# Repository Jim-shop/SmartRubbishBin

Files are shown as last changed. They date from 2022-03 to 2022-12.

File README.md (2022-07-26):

# SmartRubbishBin（智能倾倒垃圾桶）

## 仓库结构（暂定）

- `📂Arduino`文件夹存放Arduino代码
- `📂CarModel`文件夹存放小车SolidWorks模型
- `📂ROS`文件夹存放与ROS相关的代码
- `📂Tutorial`中记录一些学习笔记
- `📄.gitignore`中填写不需要被git管理的文件/文件夹
- `📄Makefile`配置自动构建或执行自动化任务
- `📄README.md`就是本文件

## 开发环境

- Ubuntu == 20.04 ~ 20.04.4
- Arduino IDE >= 1.8.19
- ROS1-Noetic-Desktop-Full（自带OpenCV)
- ros-noetic-serial包
- SolidWorks == 2021
- Arduino Uno 一片
- L298N 一片
- 激光雷达一个

## 食用指南

### 1. 首先将仓库克隆到本地：

```bash
cd 父路径（自选）
git clone git@github.com:Jim-shop/SmartRubbishBin.git
```
> 没有配置公钥的话可以用HTTPS克隆。

这样，`git`会在自选的`父路径`下新建一个以这个仓库名命名的文件夹，然后将仓库内容以及文件历史信息等克隆到这个文件夹里。

注意，此仓库会用到一些预训练的神经网络，这些神经网络的权重文件比较大，不方便上传Github，请在网络上下载后手动放到相应地方。

### 2. 配置环境

#### （1）Arduino IDE 从官网下载安装
apt源得到的版本较为老旧。
#### （2）Ros Noetic和Serial包参考以下命令安装
```bash
sudo apt install ros-noetic-desktop-full
sudo apt install ros-noetic-serial
```
#### （3）给设备起别名，防止设备号乱了
首先执行
```bash
lsusb
```
得到设备号如`10c4:ea60`。
进入`cd /etc/udev/rules.d`进入目录，新建一个`usb.rules`文件，内容为
```shell
KERNEL=="ttyUSB*",ATTRS{idVendor}=="10c4",ATTRS{idProduct}=="ea60",MODE:="0777",SYMLINK+="laser"
KERNEL=="ttyUSB*",ATTRS{idVendor}=="1a86",ATTRS{idProduct}=="7523",MODE:="0777",SYMLINK+="uno"
```
然后重启udev：
```bash
service udev reload
service udev restart
```
重新插拔USB设备即可。

### 3. 编译
   
为了节省空间和保护隐私，仓库里只有源代码，要生成可执行程序，请参照以下操作：

#### （1）逐一构建
- 如果要生成ROS的可执行文件，请：
    ```bash
    cd 刚克隆下来的仓库路径/ros/
    catkin_make
    ```
- 如果要生成Arduino固件，请直接使用Arduino IDE打开ino文件进行编译烧录。

#### （2）批量构建
将来可能有很多不同种类的文件/代码（当然现在只有ROS代码和Arduino代码两种），逐一编译生成很麻烦。因此在仓库根目录下配置了一个`Makefile`，在其中填入了各种文件的编译方法，只要在根目录下输入：
```bash
cd 刚克隆下来的仓库路径/
make
```
这样所有项目就可以一次性编译完成。

> 顺便，`Makefile`中也配置了清理功能，
> 只要在根目录下执行：
> ```bash
> make only_source
> ```
> 就可以删除编译结果，只保留源代码。

### 4. 开发

参见[Git协作开发指南](Tutorial/Git协作开发指南.md)。

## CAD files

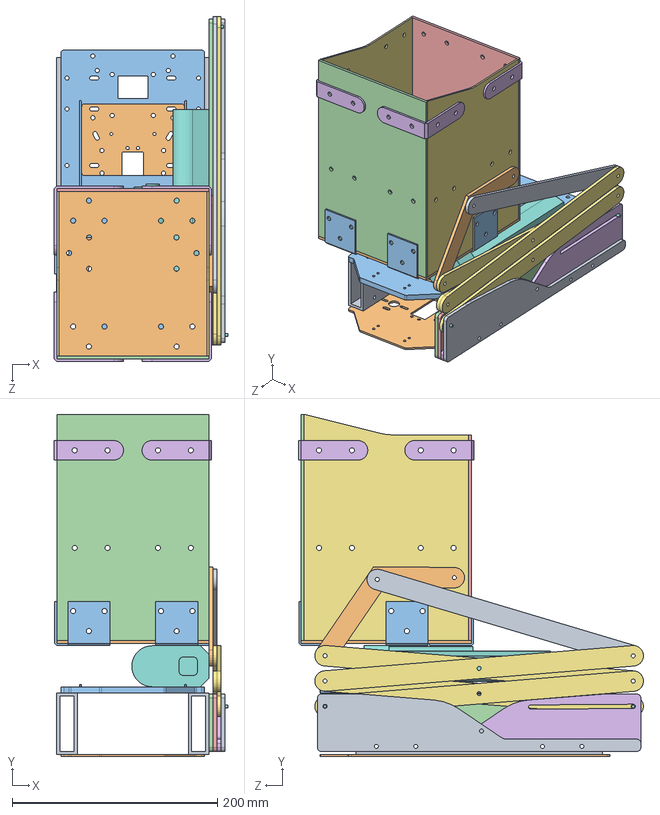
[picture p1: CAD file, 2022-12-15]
CarModel/完整机构.SLDASM
169.0 x 333.2 x 335.8 mm
钢扁管（x2） x 2
小车底板
小车底板(3d打印二层）
滑槽板（内侧）
滑槽板（中间）
滑槽板（外侧）
连杆 x 4
塞打螺栓 x 2
倾倒杆2
底板
角铁2 x 6
侧面板
侧面板2
角铁1 x 4
侧板2 x 2
底座
滑槽板（最外）
倾倒杆

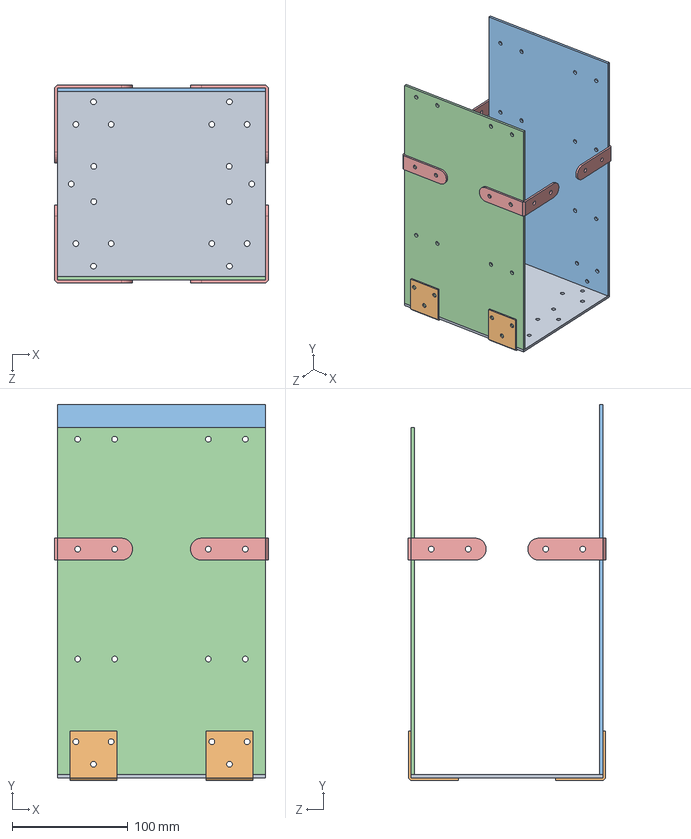
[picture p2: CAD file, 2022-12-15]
CarModel/垃圾桶2.0.SLDASM
185.0 x 325.0 x 171.0 mm
底板
角铁2 x 4
侧面板
侧面板2
角铁1 x 4

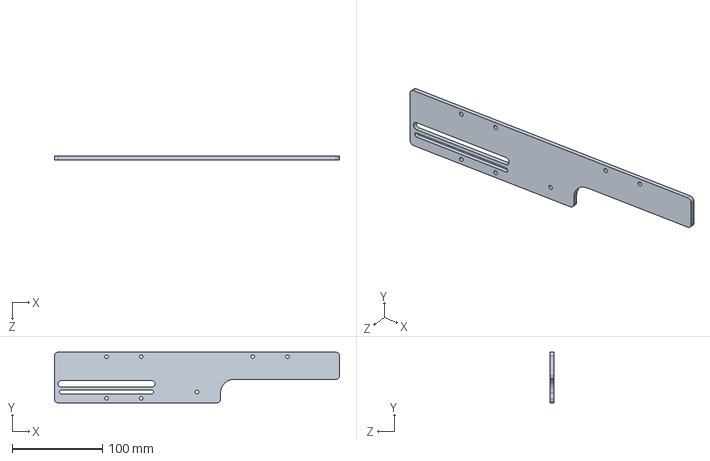
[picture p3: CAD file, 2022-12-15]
CarModel/滑槽板（外侧）.SLDPRT
315.0 x 56.0 x 4.00 mm

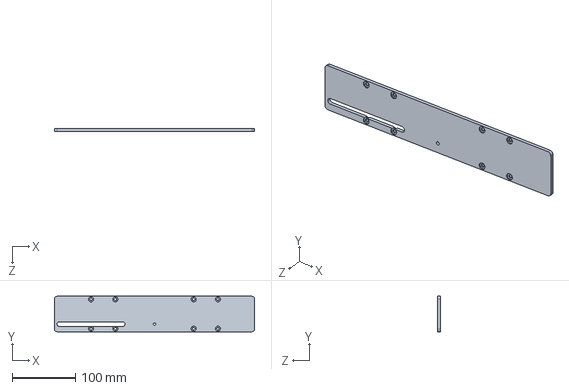
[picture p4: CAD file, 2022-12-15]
CarModel/滑槽板（内侧）.SLDPRT
315.0 x 56.0 x 4.00 mm

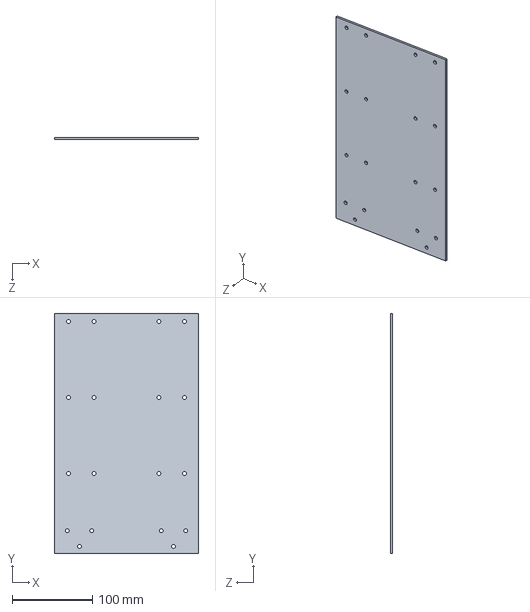
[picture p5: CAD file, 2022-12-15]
CarModel/侧面板2.SLDPRT
180.0 x 300.0 x 3.00 mm

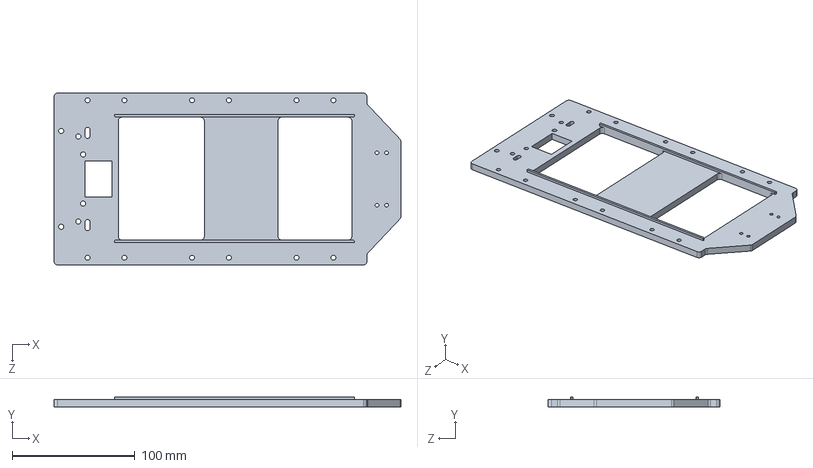
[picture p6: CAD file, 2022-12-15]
CarModel/小车底板(3d打印二层）.SLDPRT
282.3 x 8.00 x 140.0 mm

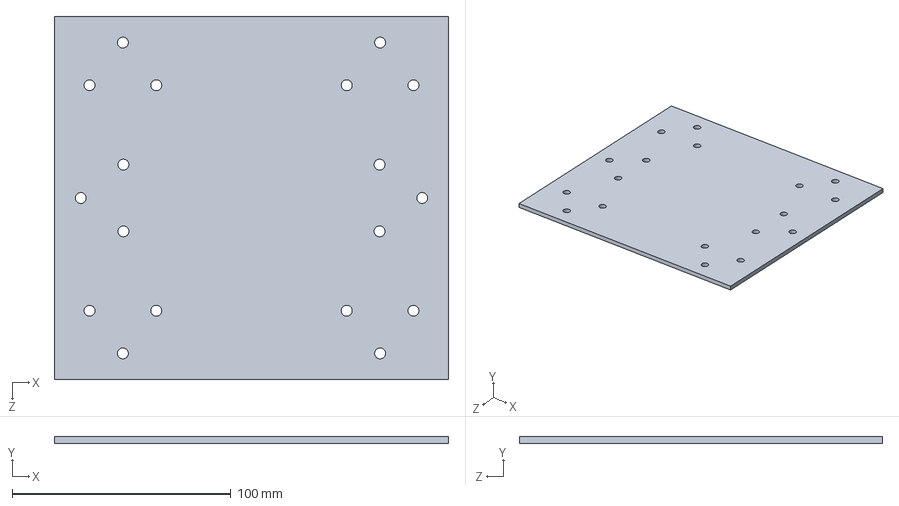
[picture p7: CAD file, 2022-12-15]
CarModel/底板.SLDPRT
180.0 x 3.00 x 166.0 mm

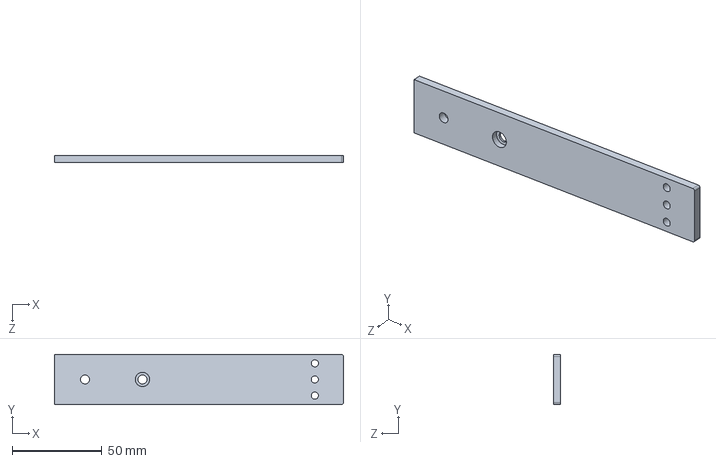
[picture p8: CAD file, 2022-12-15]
CarModel/推动杆.SLDPRT
161.0 x 27.8 x 4.00 mm

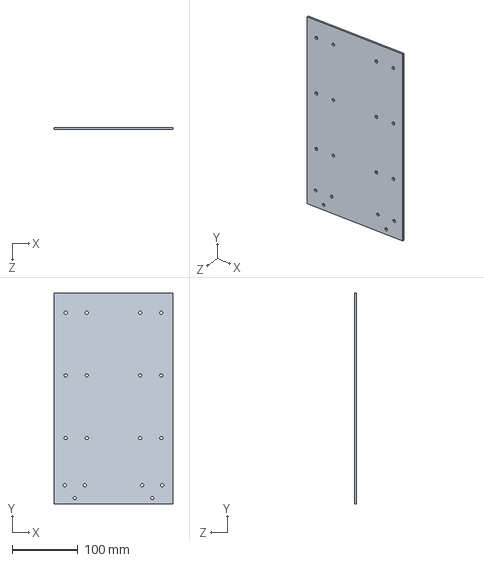
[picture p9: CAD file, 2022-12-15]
CarModel/侧面板.SLDPRT
180.0 x 320.0 x 3.00 mm

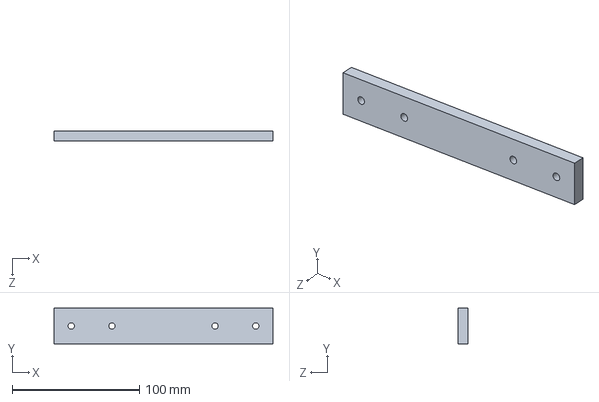
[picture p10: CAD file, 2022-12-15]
CarModel/推动承杆.SLDPRT
172.0 x 28.0 x 8.00 mm

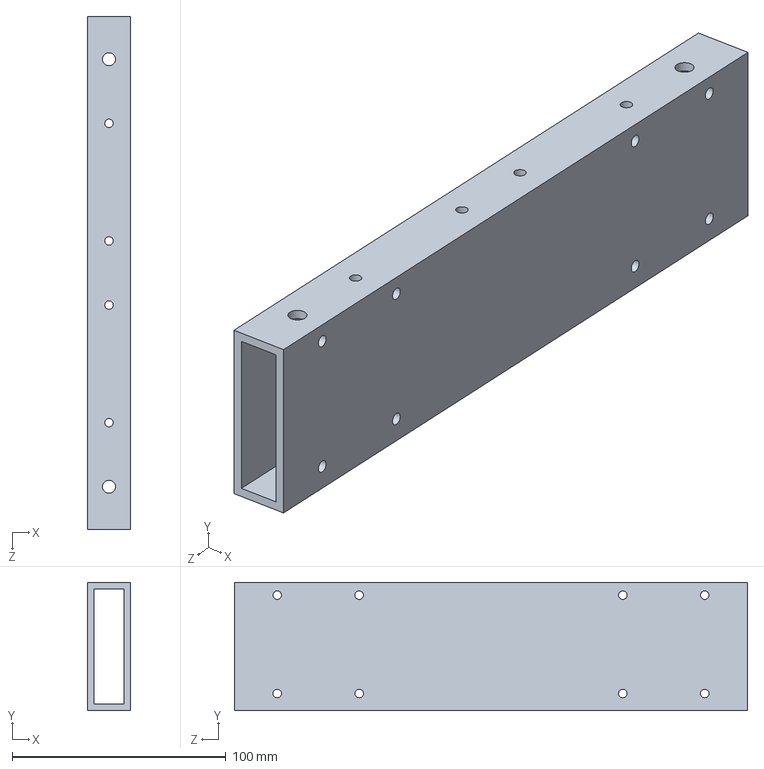
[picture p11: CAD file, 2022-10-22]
CarModel/钢扁管（x2）.SLDPRT
20.0 x 60.0 x 240.0 mm

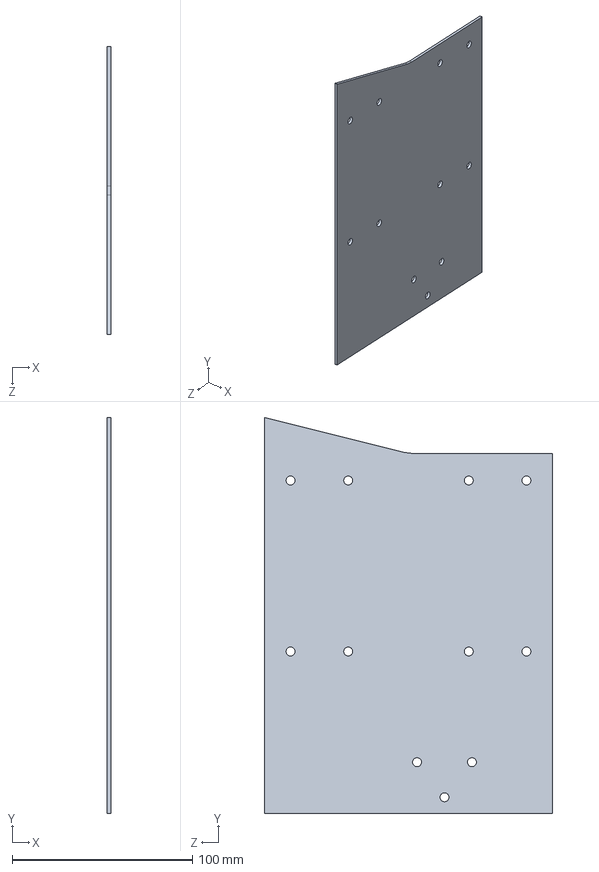
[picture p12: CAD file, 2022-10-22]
CarModel/侧板2.SLDPRT
2.00 x 220.0 x 160.0 mm

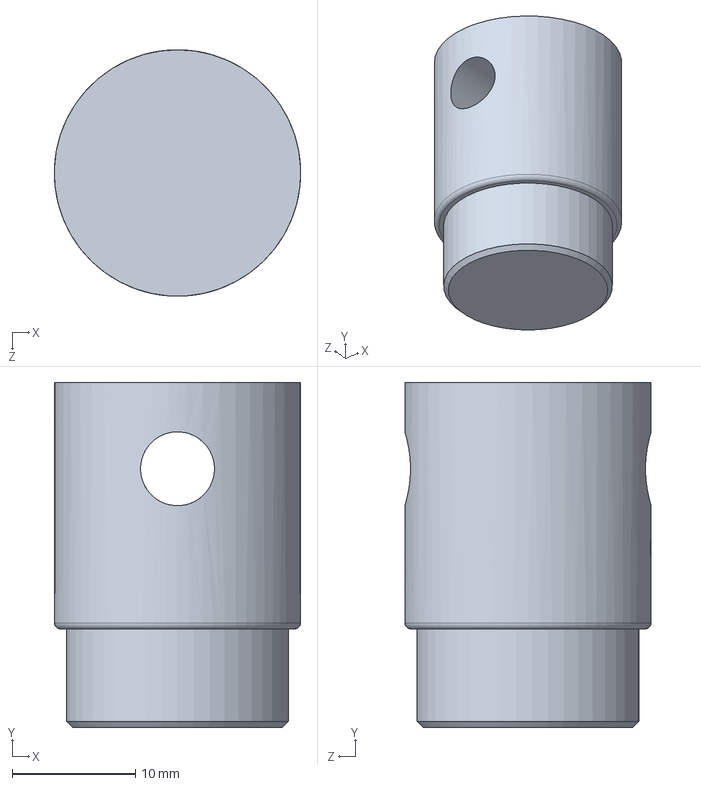
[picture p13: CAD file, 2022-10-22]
CarModel/接头T1.SLDPRT
20.0 x 28.0 x 20.0 mm

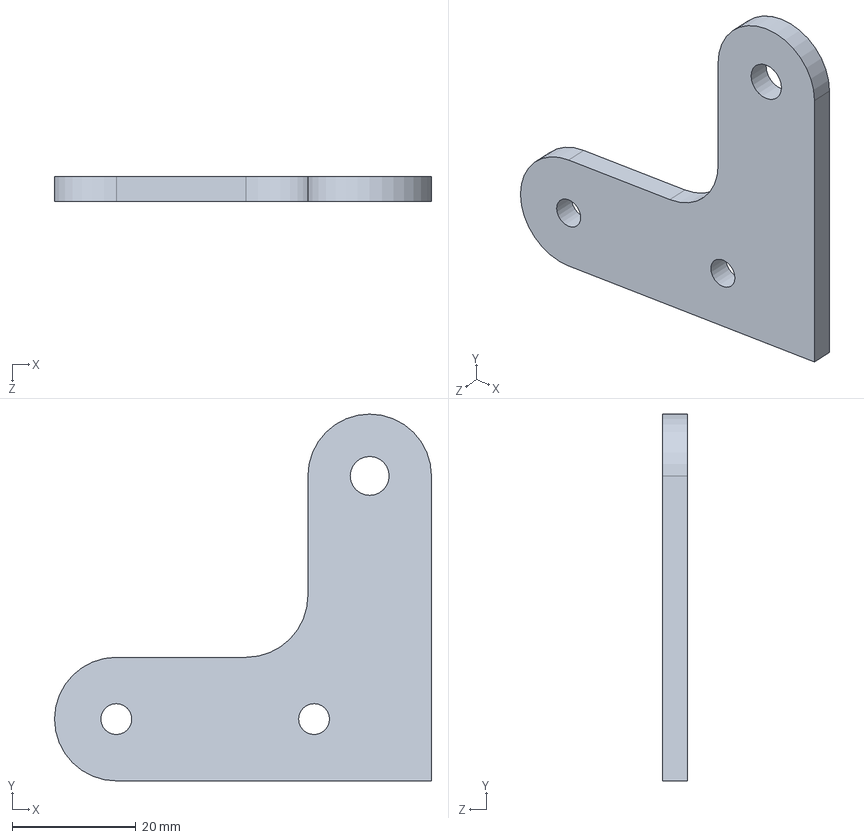
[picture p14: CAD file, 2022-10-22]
CarModel/推杆支撑.SLDPRT
61.0 x 59.4 x 4.00 mm

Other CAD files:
CarModel/滑槽板（最外））.SLDPRT
CarModel/滑槽板（中间）.SLDPRT
CarModel/角铁2.SLDPRT
CarModel/钢管.SLDPRT
CarModel/倾倒杆2.SLDPRT
CarModel/倾倒杆（叉车）.SLDPRT
CarModel/塞打螺栓.SLDPRT
CarModel/小车底板.SLDPRT
CarModel/底座.SLDPRT
CarModel/杆.SLDPRT
CarModel/角铁1.SLDPRT
CarModel/连杆2.SLDPRT

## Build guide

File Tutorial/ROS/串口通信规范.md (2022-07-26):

# 串口通信规范

## 串口模式

- 波特率：57600
- 数据位：8
- 奇偶校验：偶校验
- 停止位：1

接收端2ms速度轮询（因为最长的消息需要2.9ms传输完成）；如果有循环发送需求的话，发送端5ms速度循环发送，需要等待发送缓冲区flush。

## 消息规范

### 1. 启动信号
发送端发出`0x55 0xaa`两个字节，标识串口通信开始。

### 2. 发送数据类型
由于Arduino要接收Twist消息和推杆信息两种信息，约定发送一个字节，标识数据类型：
- Twist: `0xa0`
- 推杆信息: `0xa1`

Arduino只需要发出action这一种信息，因此不需要标识数据类型。
<!-- Arduino只需要发出里程计（Odom）这一种信息，因此不需要标识数据类型。 -->

### 3. 数据本体
Arduino和上位机树莓派、PC都是IEEE 754型浮点数、小端序，不过Arduino的double实际上是float。因此，两方可以从小端到大端逐字节直接发送接收二进制数据。

#### Twist
由于我们在平面上运动，Twist只需要收发
- linear_x
- linear_y
- angular_z

这三种数据。照顾到Arduino没有double型数据，两方都发送float，按以上顺序收发这三个float，共12字节。

#### 推杆信息
只有一个bool型，指示是否给推杆供电。

#### action信息
只有一个bool型，指示倾倒是否完成。

#### 里程计Odom
包含五个信息：
- x_final
- y_final
- th_final
- velocity1
- velocity2

同样都是float，按以上顺序发送。

### 4. 校验码
在数据本体发送完毕后，发送两字节的校验码，第一个字节内容是之前发送的所有字节的异或，第二个字节的内容是之前发送的左右字节的加和（不包括第一个字节校验码）。

> 例如，Arduino接收到的一个推杆伸出的信息是：
> `0x55 0xaa 0xa1 0x01`，
> 那么它接下来要接收到两个校验码，第一个是
> `0x55 ^ 0xaa ^ 0xa1 ^ 0x01 = 0x5f`，
> 第二个是
> `0x55 + 0xaa + 0xa1 + 0x01 = 0xa1`，
> 两个校验码无误才能确认接收消息。

## 错误处理规范

### 接收方
接收方轮询的具体操作方法是，每次调用轮询，用一个循环读取，一个字节一个字节读取，直到将串口缓冲区读空，读空后退出轮询函数。注意，轮询函数一次调用不一定能完整读取一条消息，因此内部需要用一个线性状态机处理。

首先，标志变量置-3。

当标志位为-3时，若串口输入`0x55`时，标志位改-2，否则，维持-3。

当标志位为-2时，若串口输入`0xaa`时，标志位改-1，否则，标志位改回-3。

当标志位为-1时，若串口输入`0xa0`时，进入Twist读取模式，标志位改0；若串口输入为`0xa1`时，进入推杆读取模式，标志位改0；否则，标志位改回-3。
需要另起一个标志位，记录当前是Twist读取模式还是推杆读取模式。

在Twist读取模式下，读取12个字节，标志位从0增加到12。
当标志位为12时，核验本地计算的异或校验码是否和传入的异或校验码一致，一致则标志位改13，否则标志位改-3，并清空串口读取缓冲区，因为可能发生了数据错位的情况。
当标志位为13时，核验本地的加和校验码是否与传入一致，一致则宣告读取成功，标志位归-3，否则标志位也归-3，但需清空串口读取缓冲区。

在推杆读取模式下，同理。

### 发送端
监测串口是否断联（Serial::IOException），如是，循环重开串口。

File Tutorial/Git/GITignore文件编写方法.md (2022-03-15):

# .gitignore文件编写方法

## 1. 井号开头的行是注释。
```bash
# 井号开头的行是注释。
```

## 2. 格式参照shell的glob模式
- 星号（“*”）匹配0个或任意个字符，问号（“?”）匹配一个任意字符
  ```bash
  doc/*.txt # 匹配doc/notes.txt，但不会匹配doc/server/arch.txt
  ```
- 使用两个星号表示匹配任意中间目录
  ```bash
  a/**/z #匹配a/z，a/b/c/z等
  ```
- \[abc\]匹配任何一个列在方括号中的字符。
  简写形式\[0-3a-c\]相当于\[0123abc\]

## 3. 其他规则：
- 默认是递归匹配。
- 以斜杠（“/”）开头，阻止递归匹配。
  ```bash
  /TODO # 只忽略当前目录下的 TODO 文件，而不忽略 subdir/TODO
  ```
- 以斜杠（“/”）结尾，指定只匹配目录。
  ```bash
  build/  # 忽略任何目录下名为 build 的文件夹
  ```
- 以叹号（“!"）开头，表示取反，告诉Git不要忽略这个文件或目录。
  ```bash
  !lib.a  # 跟踪所有的 lib.a，即便你在前面忽略了 .a 文件
  ```

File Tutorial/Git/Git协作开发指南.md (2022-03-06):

# Git协作开发指南

以命令行讲解为主。

现在有很多Git的图形界面客户端，和敲命令行原理上是一样的，只是把输命令的过程给做成了一个个按钮。

## 概述

使用Git进行协作开发的流程一般是
1. 首先从远程服务器拉取最新的主分支
2. 从主分支创建本地新分支，切换到这个新分支上
3. 按常规的方式进行开发
4. 新分支开发有了进展，在新分支内本地提交
5. 开发测试正常后，切换到主分支，整合，推送

## 1. 拉取
```bash
cd 刚克隆下来的仓库路径/
git pull
```

## 2. 创建并切换到新分支
```bash
cd 刚克隆下来的仓库路径/
git checkout -b 新分支名（自拟）
```

## 3. 开发
切换分支后，先暂时不用管Git，直接按照常规的方法进行开发就行了，不认识Git的时候怎么开发，现在就怎么开发。

## 4. 提交
```bash
cd 刚克隆下来的仓库路径/
git commit -a 需要提交的文件/目录 -m "关于本次提交的说明（自拟）"
```
这样就把开发的成果保存到Git版本管理库中了。
> `需要提交的文件/目录`应该有哪些？
>
> 应该只有源代码。你编译出的内容一是可能存在兼容性问题，比如只能在你的电脑上执行，其他电脑上会出现问题，二是为了保持仓库简洁，出于这两点原因，请不要上传。

> **但是每次手敲文件好麻烦呀！**
> 
> 其实可以把不需要提交的文件/目录名添加到仓库根目录下的`.gitignore`文件中，这样这些文件就会被Git忽略。
> 于是就可以使用这条命令：
> ```bash
> git commit -a -m "关于本次提交的说明（自拟）"
> ```
> 把`需要提交的文件/目录`省略，这代表仓库根目录。
> 这样Git就会把`.gitignore`文件中记录的文件/目录之外的所有文件添加到Git版本管理库中。

## 5. 推送
开发测试正常后，可以切换到主分支，整合，推送。
```
cd 刚克隆下来的仓库路径/
git checkout master
git merge 之前自拟的新分支名
git push
```

> 其实不切换到主分支，直接从新分支上向远程推送也是可以的，命令请查阅Git帮助。但是一般来说整合到主分支推送会更方便一点。

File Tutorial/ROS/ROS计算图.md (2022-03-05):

# ROS 计算图简介

ROS 程序运行之后，反应不同的节点之间互相收发消息形成的关系的图就是计算图。

## 计算图工具

ROS 中提供了一个实用的工具`rqt_graph`来查看计算图。
`rqt_graph`是`rqt`程序包中的一部分。

## 计算图查看

```bash
rosrun rqt_graph rqt_graph
```

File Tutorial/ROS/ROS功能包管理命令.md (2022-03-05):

# ROS 功能包管理命令

## 1. 增

创建新的ROS功能包
```bash
catkin_create_pkg 自定义包名 依赖包
```

安装 ROS功能包
```bash
sudo apt install xxx
```

## 2. 删

删除某个功能包
```bash
sudo apt purge xxx
```

## 3. 查

列出所有功能包
```bash
rospack list
```

查找某个功能包是否存在，如果存在返回安装路径
```bash
rospack find 包名
```

进入某个功能包
```bash
roscd 包名
```

列出某个包下的文件
```bash
rosls 包名
```

搜索某个功能包
```bash
apt search xxx
```

## 4. 改

修改功能包文件（需要安装 Vim）
```bash
rosed 包名 文件名
```

## 5. 执行

### (1) roscore
   
roscore 是 ROS 的系统先决条件节点和程序的集合， 必须运行 roscore 才能使 ROS 节点进行通信。

```bash
roscore
```
或指定端口号
```bash
roscore -p xxxx
```

roscore 将启动:
- ros master
- ros 参数服务器
- rosout 日志节点

### (2) rosrun
 
 运行指定的ROS节点
 ```bash
 rosrun 包名 可执行文件名
 ```

### (3) roslaunch
 执行某个包下的 launch 文件
 ```bash
 roslaunch 包名 launch文件名
 ```

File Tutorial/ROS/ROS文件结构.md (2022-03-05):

`WorkSpace` 工作空间目录（名称自拟）

> `build` 编译空间
>
> 用于存放CMake和catkin的缓存信息、配置信息和其他中间文件。

> `devel` 开发空间
> 
> 用于存放编译后生成的目标文件，包括头文件、动态&静态链接库、可执行文件等。

> `src` 源码
> 
> > `CMakeLists.txt` 编译的基本配置
> > 
> > 是个符号链接，指向ROS包内部
>
> > `package` 功能包文件夹（名称自拟）
> > 
> > (ROS基本单元)包含多个节点、库与配置文件，包名所有字母小写，只能由字母、数字与下划线组成
> > 
> > > `CMakeLists.txt` 配置编译规则
> > >
> > > 比如源文件、依赖项、目标文件
> > 
> > > `package.xml` 包信息
> > >
> > > 比如:包名、版本、作者、依赖项...(以前版本是 manifest.xml)
> > 
> > > `scripts` 储存Python脚本
> > 
> > > `src` 存储C++源文件
> > 
> > > `include` 头文件
> > 
> > > `msg` 消息通信格式文件
> > 
> > > `srv` 服务通信格式文件
> > 
> > > `action` 动作格式文件
> > 
> > > `launch` roslaunch配置文件
> > >
> > > 可一次性运行多个节点 
> > 
> > > `config` 配置信息

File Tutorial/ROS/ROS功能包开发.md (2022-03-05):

# ROS 功能包开发流程

## 一、准备工作空间
   
1. 将命令行工作路径移动到所需用作工作空间的文件夹
   
    ```bash
    cd 自定义工作空间文件夹名
    ```

2. 在那个工作空间中新建一个`src`文件夹，用来保存源代码

    ```bash
    mkdir src
    ```

3. 调用ROS工具初始化工作空间 *（注意此时工作路径不是在`src`中）*
   
    ```bash
    catkin_make
    ```

   此时会在src文件夹下生成一个`CMakeLists.txt`的符号链接

## 二、创建功能包

进入`src`目录，创建ROS功能包，并添加依赖

```bash
cd src
catkin_create_pkg 自定义功能包名 依赖项1 依赖项2 ...
```

开发Cpp应用，需要添加`roscpp`依赖项，Python则需要`rospy`依赖项。一般来说还要引入`std_msgs`标准消息库。

> 执行完`catkin_create_pkg`后，工作空间中的文件就会多起来，其中：
> 
> - `build`文件夹存放已经编译完成的ROS功能包
> - `devel`文件夹中存放运行功能包所需的一些环境配置文件
> - `src`文件夹就是我们自行创建的那个，
>   但是里面会新建一个功能包文件夹，
>   文件夹的名字就是我们刚刚自定义的功能包名。

## 三、编写功能包

> 功能包文件夹结构：
>
> - `include`文件夹中保存Cpp的头文件
> - `src`文件夹中保存Cpp的源代码
> 
> 以上是ROS构造工具的默认结构。
> 为了方便，不要改动文件夹名和它们的用途。
> 
> 另外，还可以自行新建文件夹：
> - `scripts`，用来存放Python脚本。
> - `launch`，用来存放launch文件，用于批量启动节点。

### （一）Cpp程序编写

1. 在功能包文件夹下`src`中新建Cpp源文件（名字自定义），填入代码。简明示例如下：
   
    ```cpp
    #include "ros/ros.h"
    // 头文件位于/opt/ros/noetic/include/**

    int main(int argc, char *argv[])
    {
        /* 第一步：执行ROS节点初始化
        * ros::init([传递命令行参数],节点名称)
        */
        ros::init(argc, argv, "example");

        /* 第二步（可选）：创建ROS节点句柄
        */
        ros::NodeHandle n;

        ROS_INFO("hello world!");

        /* 离别时：报平安
        */
        return 0;
    }
    ```

2. 编辑功能包文件夹下的`CMakeLists.txt`，参照其注释，修改编译配置：

    ```cmake
    add_executable(编译成什么名字 src/源文件名.cpp)
    target_link_libraries(编译成什么名字
        ${catkin_LIBRARIES}
    )
    ```

3. 进入工作空间根目录，执行编译

    ```bash
    cd 工作空间文件夹
    catkin_make
    ```

### （二）Python脚本编写

1. 可以在功能包文件夹中新建一个`scripts`目录用以存放脚本。

    ```bash
    cd 功能包文件夹
    mkdir scripts
    ```

2. 在`scripts`文件夹中新建Python脚本，名字自拟。示例如下：

    ```python
    #! /bin/python3
    """
    上面一行按格式填写Python解释器路径，
    这样，当赋予这个脚本文件可执行权限时，
    在控制台敲入此文件名并回车，
    控制台就能根据此行找到对应的解释器，
    自动调用它执行这个脚本，而不需要我们手工指定。
    """

    import rospy #rospy在安装ros时已经安装好

    if __name__ == "__main__":
        # 第一步：给定节点名，初始化节点
        rospy.init_node("examplePY")
        rospy.loginfo("Hello world.")
    ```

3. 为Python文件添加可执行权限
   
    ```bash
    chmod +x 脚本文件名.py
    ```

4. 编辑功能包文件夹下的`CMakeLists.txt`，参照其注释，修改编译配置：

    ```cmake
    catkin_install_python(PROGRAMS
        scripts/脚本文件名.py
        DESTINATION ${CATKIN_PACKAGE_BIN_DESTINATION}
    )
    ```

    > Python虽然不需要编译，但是可以通过此步生成环境配置，
    > 方便互相调用。

## 四、执行功能包

### （一）手工执行

1. 首先系统中要有一个启动的`roscore`。如果没有，执行：
   
    ```bash
    roscore
    ```

    > 不使用“小技巧”，直接执行`roscore`，会占用一个控制台窗口。
    >
    > 若还要使用控制台应用，需要新开一个控制台窗口。

2. 进入工作空间文件夹，载入`devel`文件夹下的环境配置脚本

    ```bash
    cd 工作空间
    source ./devel/setup.bash
    ```

    > 如果使用的是`Zsh`，就载入`setup.zsh`。
    >
    > 注意，对于每个控制台，在运行下一步之前都要载入这个脚本。
    > 如果懒得每次输入，可以把这指令加入到`~/.bashrc`，`~/.zshrc`等里面。 

3. 执行
   
    ```bash
    rosrun 包名 可执行文件
    ```

    > 对于Cpp应用，`可执行文件`是`编译成的名称`；
    > 
    > 对于Python脚本，`可执行文件`就是`脚本名称.py`

### （二）批处理执行

0. **【准备工作】** 在功能包文件夹下新建`launch`文件夹，在其中添加launch文件（名称自拟），文件内容示例：
      
    ```xml
    <launch>
        <!--pkg=功能包 type=被运行的功能包文件 name=为节点命名 output=设置日志的输出目标-->
        <node pkg="Example" type="eg.py" name="launch_eg_py" output="screen" />
        <node pkg="Example" type="Example_node" name="launch_eg_cpp" output="screen" />

        <node pkg="turtlesim" type="turtlesim_node" name="t1" />
    </launch>
    ```

1. 不需要特意启动`roscore`。`roslaunch`会自动启动它。

2. 进入工作空间文件夹，载入`devel`文件夹下的环境配置脚本

    ```bash
    cd 工作空间
    source ./devel/setup.bash
    ```

    > 如果使用的是`Zsh`，就载入`setup.zsh`。
    >
    > 注意，对于每个控制台，在运行下一步之前都要载入这个脚本。
    > 如果懒得每次输入，可以把这指令加入到`~/.bashrc`，`~/.zshrc`等里面。 

3. 运行launch文件

    ```bash
    roslaunch 包名 launch文件名
    ```

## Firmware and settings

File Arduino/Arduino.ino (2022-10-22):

#include <MsTimer2.h>
#include <math.h>

#include "config.hpp"
#include "constants.hpp"

#include "console.hpp"

//-----------------------------------全局变量
float target1 = 1;            //左 保守
float target2 = -1;           //右 速度
volatile int encoderVal1 = 0; //编码器 1 值
volatile int encoderVal2 = 0; //编码器 2 值
float velocity1;              //转速 1
float velocity2;              //转速 2
volatile float x_final = 0;
volatile float y_final = 0;
volatile float th_final = PI / 2;

bool shouldPull = false; // 收到的，指示是否应该启动推杆
bool isSuccess = false;  // 发送的，指示Arduino是否已经完成动作

float linear_x = 1, linear_y = -1, angular_z = 0;

/////////////////////////////////////
////         程序代码部分          ////
/////////////////////////////////////

//-----------------------------------上位机数据接收
void read()
{
    enum DataType : uint8_t
    {
        Twist = 0xa0,
        Bool = 0xa1,
    };
    union TwistBuf
    {
        float f[3]; // arduino 的 double 就是 float
        uint8_t i[sizeof(f)];
    };

    static DataType currMod;
    static int_fast8_t currByteNo = -3;
    static bool needReset = false, needFlushInput = false;
    static uint8_t checkCode1 = 0x55 ^ 0xaa, checkCode2 = 0x55 + 0xaa;
    static TwistBuf twistBuf;
    static bool boolBuf;

    int byteBuf = Serial.read();
    for (uint8_t currByte = byteBuf; byteBuf >= 0; byteBuf = Serial.read(), currByte = byteBuf)
    {
        if (currByteNo < 0)
        {
            switch (currByteNo)
            {
            case -3:
                if (currByte == 0x55)
                    currByteNo++;
                break;

            case -2:
                if (currByte == 0xaa)
                    currByteNo++;
                else
                    currByteNo = -3;
                break;

            case -1:
                if (currByte == Twist || currByte == Bool)
                {
                    currMod = (DataType)currByte;
                    currByteNo++;
                    checkCode1 ^= currByte;
                    checkCode2 += currByte;
                }
                else
                    currByteNo = -3;
                break;
            }
        }
        else
        {
            if (currMod == Twist)
            {
                switch (currByteNo)
                {
                case sizeof(twistBuf):
                    if (checkCode1 == currByte)
                        currByteNo++;
                    else
                        needReset = true, needFlushInput = true;
                    break;

                case sizeof(twistBuf) + 1:
                    needReset = true;
                    if (checkCode2 == currByte)
                    {
                        linear_x = twistBuf.f[0];
                        linear_y = twistBuf.f[1];
                        angular_z = twistBuf.f[2];
                        target1 = linear_x - angular_z * d_wheel / 2;
                        target2 = linear_x + angular_z * d_wheel / 2;
                    }
                    else
                        needFlushInput = true;
                    break;

                default:
                    twistBuf.i[currByteNo] = currByte;
                    currByteNo++;
                    checkCode1 ^= currByte;
                    checkCode2 += currByte;
                    break;
                }
            }
            else
            {
                switch (currByteNo)
                {
                case 1:
                    if (checkCode1 == currByte)
                        currByteNo++;
                    else
                    {
                        needReset = true;
                        needFlushInput = true;
                    }
                    break;

                case 2:
                    needReset = true;
                    if (checkCode2 == currByte)
                        shouldPull = boolBuf;
                    else
                        needFlushInput = true;
                    break;

                case 0:
                    boolBuf = currByte;
                    currByteNo++;
                    checkCode1 ^= currByte;
                    checkCode2 += currByte;
                    break;
                }
            }
        }

        if (needReset)
        {
            currByteNo = -3;
            checkCode1 = 0x55 ^ 0xaa;
            checkCode2 = 0x55 + 0xaa;
            needReset = false;
        }
        if (needFlushInput)
        {
            while (Serial.available() > 0)
                Serial.read();
            needFlushInput = false;
        }
    }
}

//-----------------------------------Odom和tf数据发送
inline void Publish(void)
{
    float dis_left = 2 * PI * ((float)encoderVal1 / pulse_round) * r_wheel;
    float dis_right = 2 * PI * ((float)encoderVal2 / pulse_round) * r_wheel;
    float d_x = ((dis_left + dis_right) / 2) * sin(th_final);
    float d_y = ((dis_left + dis_right) / 2) * cos(th_final);
    float d_th = (dis_right - dis_left) / d_wheel;
    dis_left = 0;
    dis_right = 0;
    x_final += d_x;
    y_final += d_y;
    th_final += d_th;

    union
    {
        float f[5]; // arduino 的 double 就是 float
        uint8_t i[sizeof(f)];
        // } buf{.f = {linear_x, y_final, th_final, velocity1, velocity2}};
    } buf{.f = {x_final, y_final, th_final, velocity1, velocity2}};
    uint8_t sentbuf[2 + sizeof(buf) + 2];
    sentbuf[0] = 0x55, sentbuf[1] = 0xaa;
    memcpy(&sentbuf[2], buf.i, sizeof(buf));
    uint8_t &checkCode1 = sentbuf[2 + sizeof(buf) + 0],
            &checkCode2 = sentbuf[2 + sizeof(buf) + 1];
    checkCode1 = checkCode2 = 0x55;
    for (int i = 1; i < 2 + sizeof(buf); i++)
        checkCode1 ^= sentbuf[i], checkCode2 += sentbuf[i];
    Serial.write(sentbuf, sizeof(sentbuf));
    /*
     uint8_t sentbuf[2 + sizeof(bool) + 2] = {
         0x55,
         0xaa,
         isSuccess,
         0x55 ^ 0xaa ^ isSuccess,
         uint8_t(0x55 + 0xaa + isSuccess),
     };
     Serial.write(sentbuf, sizeof(sentbuf));*/
}

//-------------------------------control
inline int pidController1(float targetVelocity, float currentVelocity)
{
    static float u1;
    static float u11, u12, u13;
    u11 = targetVelocity - currentVelocity;
    u1 += q0 * u11 + q1 * u12 + q2 * u13;
    if (u1 > 255)
        u1 = 255;
    if (u1 < -255)
        u1 = -255;
    u13 = u12;
    u12 = u11;
    return (int)u1;
}

inline int pidController2(float targetVelocity, float currentVelocity)
{
    static float u2;
    static float u21, u22, u23;
    u21 = targetVelocity - currentVelocity;
    u2 += q0 * u21 + q1 * u22 + q2 * u23;
    if (u2 > 255)
        u2 = 255;
    if (u2 < -255)
        u2 = -255;
    u23 = u22;
    u22 = u21;
    return (int)u2;
}

//-----------------------------------编码器中断函数
long forwards[5], backwards[5];
void getEncoder1(void) // the previous model is not very accurate
{
    static auto lastTime = millis();
    auto thisTime = millis();
    auto diffTime = thisTime - lastTime;
    if (diffTime > 4)
        diffTime = 4;
    if (digitalRead(ENCODER_A1) ^ digitalRead(ENCODER_B1))
        backwards[diffTime]++;
    else
        forwards[diffTime]++;
    lastTime = thisTime;
}
void getEncoder2(void)
{
    if (digitalRead(ENCODER_A2) ^ digitalRead(ENCODER_B2))
        encoderVal2++;
    else
        encoderVal2--;
}

//-----------------------------------定时器初始化
inline void setTimer1(void)
{
    /* 参见：https://blog.csdn.net/Wxx_Combo/article/details/113987176 */
    noInterrupts(); // 暂时关闭中断，防止打断寄存器设置
    /* CS12 CS11 CS10 = 0 0 1 代表1分频 */
    TCCR1B &= 0b11111000; // 将CS12、CS11、CS10置零
    TCCR1B |= 0b00000001; // 将CS11置1
    interrupts();         // 恢复中断
}

//-----------------------------------主函数
void setup()
{
    // 改变9,10管脚PWM频率
    setTimer1();

    // 定时接收Twist信息
    MsTimer2::set(CONTROL_PERIOD, control);
    // MsTimer2::start();

    // 电机1
    pinMode(ENCODER_A1, INPUT);
    pinMode(ENCODER_B1, INPUT);
    attachInterrupt(digitalPinToInterrupt(ENCODER_B1), getEncoder1, CHANGE);

    // 电机2
    pinMode(ENCODER_A2, INPUT);
    pinMode(ENCODER_B2, INPUT);
    attachInterrupt(digitalPinToInterrupt(ENCODER_B2), getEncoder2, CHANGE);

    pinMode(PWM1, OUTPUT);
    pinMode(PWM2, OUTPUT);
    pinMode(IN1, OUTPUT);
    pinMode(IN2, OUTPUT);
    pinMode(IN3, OUTPUT);
    pinMode(IN4, OUTPUT);

    // 设置串口频率
    Serial.begin(BAUDRATE, SERIAL_MOD);
}
// Console con;
void control()
{
    // con.parse();
    // 计算轮子1,2的速度
    velocity1 = 2 * PI * ((float)encoderVal1 / pulse_round) * r_wheel * (1000 / CONTROL_PERIOD);
    velocity2 = 2 * PI * ((float)encoderVal2 / pulse_round) * r_wheel * (1000 / CONTROL_PERIOD);
    Publish();

    // 将encoderVal1, encoderVal2归零，方便下一次计算速度
    encoderVal1 = 0;
    encoderVal2 = 0;
    read();

    int output1 = pidController1(target1, velocity1);
    int output2 = pidController2(target2, velocity2);
    if (output1 > 0)
    {
        digitalWrite(IN1, LOW);
        digitalWrite(IN2, HIGH);
        analogWrite(PWM1, output1);
    }
    else
    {
        digitalWrite(IN1, HIGH);
        digitalWrite(IN2, LOW);
        analogWrite(PWM1, -output1);
    }
    if (output2 > 0)
    {
        digitalWrite(IN3, LOW);
        digitalWrite(IN4, HIGH);
        analogWrite(PWM2, output2);
    }
    else
    {
        digitalWrite(IN3, HIGH);
        digitalWrite(IN4, LOW);
        analogWrite(PWM2, -output2);
    }
}

void loop()
{
    Serial.println("\nforward:");
    for (int i = 0; i < 5; i++)
    {
        Serial.print("\t[");
        Serial.print(i);
        Serial.print("]");
        Serial.print(forwards[i]);
    }
    Serial.println("\nbackward:");
    for (int i = 0; i < 5; i++)
    {
        Serial.print("\t[");
        Serial.print(i);
        Serial.print("]");
        Serial.print(backwards[i]);
    }
    encoderVal1 = forwards[0] * 0.9 + forwards[1] * 1 + forwards[2] * 1.3 + forwards[3] * 1.11 + forwards[4] * 1.12 -
                  backwards[0] * 1.3 - backwards[1] * 1.05 - backwards[2] * 0.9 - backwards[3] * 1 - backwards[4] * 1;
    // Serial.println(encoderVal1);
}

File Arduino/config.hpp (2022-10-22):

#ifndef _CONFIG_HPP
#define _CONFIG_HPP

//-----------------------------------串口设置
const auto BAUDRATE = 57600;
const auto SERIAL_MOD = SERIAL_8E1;

//-----------------------------------引脚设置
enum Pin
{
    ENCODER_A1 = 14, //电机 1
    ENCODER_B1 = 3,
    ENCODER_A2 = 15, //电机 2
    ENCODER_B2 = 2,
    PWM1 = 9,
    PWM2 = 11,
    IN1 = 19,
    IN2 = 18,
    IN3 = 17,
    IN4 = 16,
};

//-----------------------------------设备参数
const auto pulse_round = 160; //一圈发出的脉冲数   //2it changed from 415 to 160
const auto r_wheel = 0.025f;  // 轮子半径（米）
const auto d_wheel = 0.21f;   // 轮子distance（米）

//-----------------------------------算法参数
const auto CONTROL_PERIOD = 5; // 电机控制函数的调用周期（毫秒）
const auto LOOP_PERIOD = 0;    // 编码器轮询周期（us）
const auto Kp = 10;
const auto Ti = 5;
const auto Td = 0;

#endif

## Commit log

2022-03-05 向README.md 添加待办
2022-03-05 创建.gitignore文件
2022-03-05 markdown添加仓库结构说明
2022-03-05 添加少量项目文件的说明
2022-03-05 新增Cpp功能包笔记
2022-03-05 添加Python功能包说明
2022-03-05 补充Python部分的笔记
2022-03-05 完善了编译清理功能，并清理了编译结果
2022-03-05 完善make指令的帮助
2022-03-05 添加对roslaunch的说明
2022-03-05 添加ROS文件结构，并给以前的改名
2022-03-05 对package.xml和CMakeList.txt做了注释
2022-03-05 一点笔记
2022-03-05 CV初项目跑通了
2022-03-06 README.md格式调整
2022-03-06 新建 CarModel
2022-03-15 教程分类
2022-04-27 适配yolov3
    [yolov3.cfg]
2022-07-21 new arduino
2022-07-23 ros文件夹改名
    [yolov3.cfg]
2022-07-23 server包维护
2022-07-26 arduino 和 server 传递 bool
2022-07-26 arduino -> 上位机
2022-07-26 设备起别名
